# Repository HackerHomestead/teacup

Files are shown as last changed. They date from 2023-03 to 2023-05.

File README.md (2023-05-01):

# Tea Cup Tinker Board

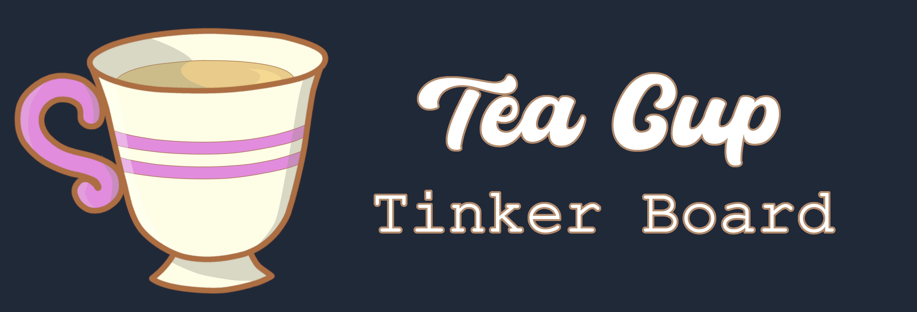
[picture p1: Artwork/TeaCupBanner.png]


The *Tea Cup* is a Tinker Board built on the *Ingenic T31* MIPS CPU, which is
specialised for Video & Audio Applications, and has highly integrated support
for multiple interfaces, LCD's, SD Card, Ethernet and more.

Designed with the community in mind, the *Tea Cup* is going to be ideal for
Kids, Tweens and Teens, and adults alike, to tinker with hardware and software
inside of an interface designed with ease-of-use and simplicity, but never 
locking the user down to a limited API or enviroment.

This project is currently in alpha, with a small team working on it, you can
join our [commuinty Discord Server](https://discord.gg/nxjvqgFQgJ)

----
## RevA Board Pictures
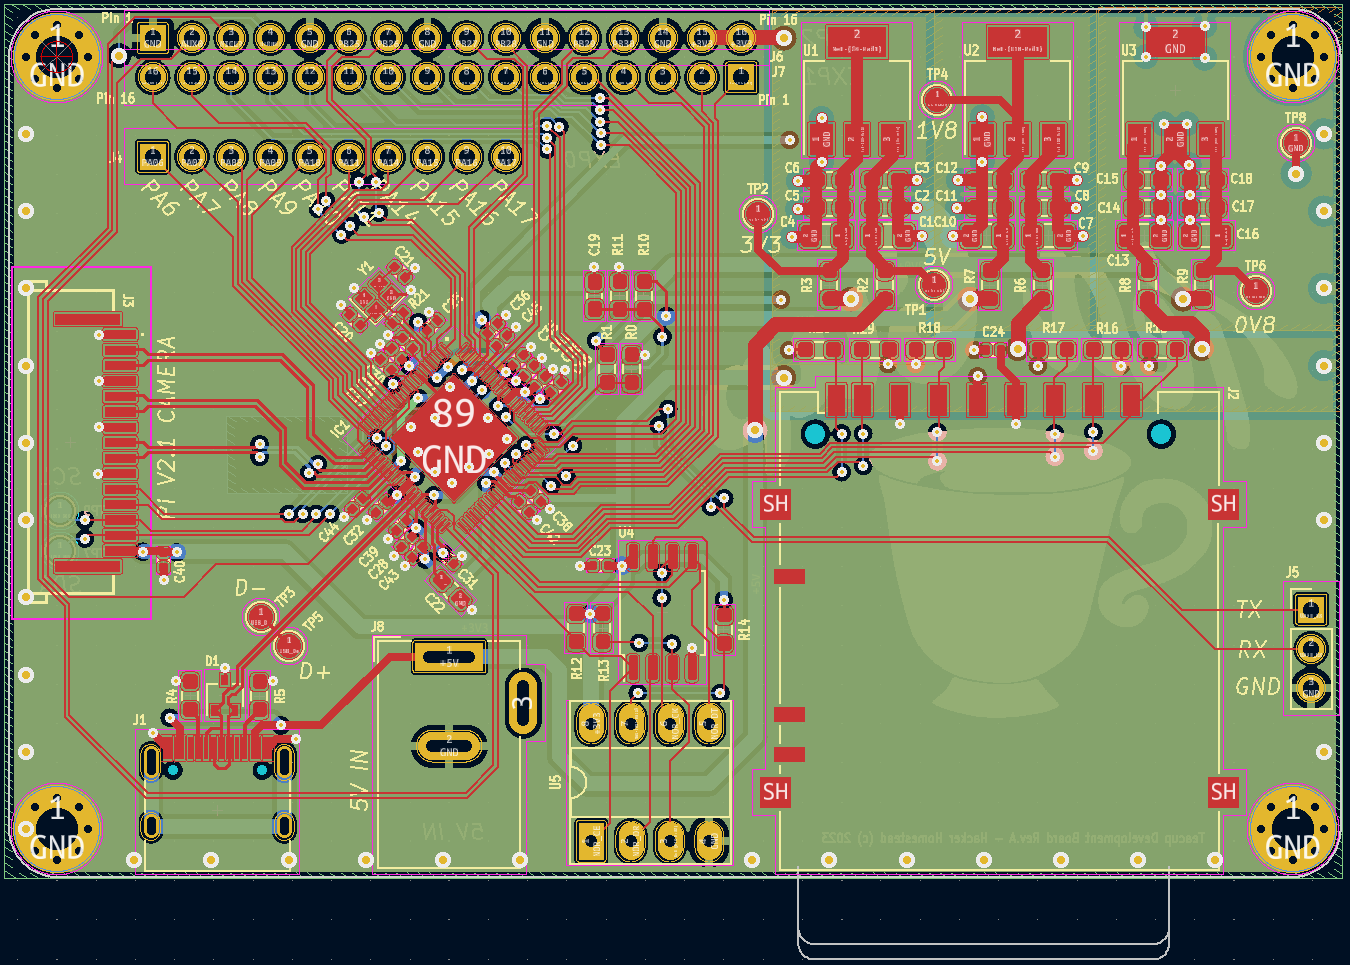
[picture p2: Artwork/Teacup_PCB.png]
boardpic1

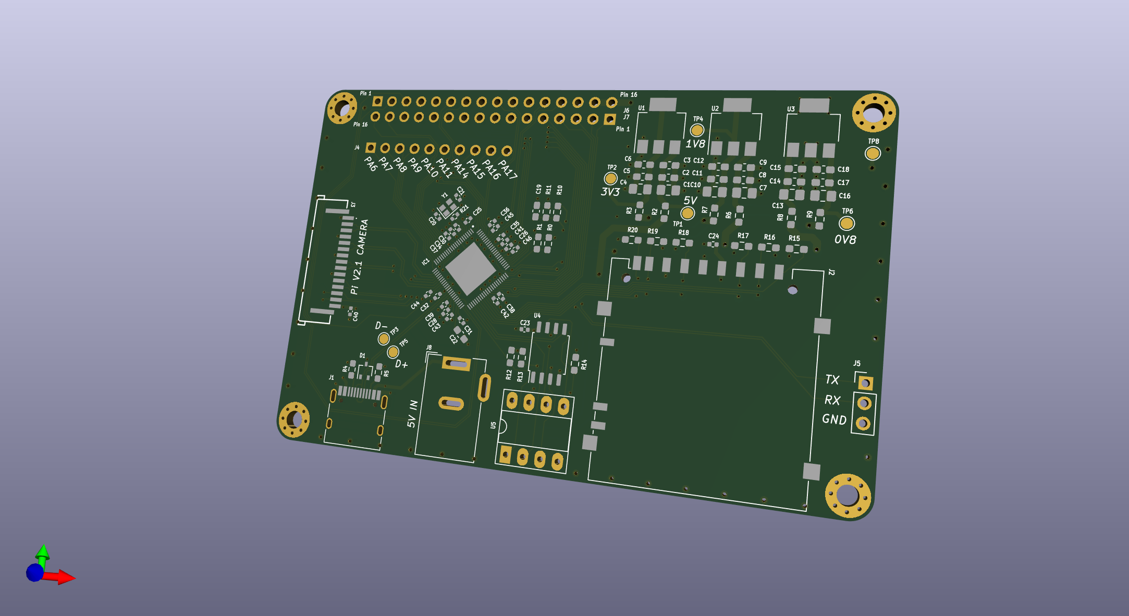
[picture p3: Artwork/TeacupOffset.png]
boardpic2

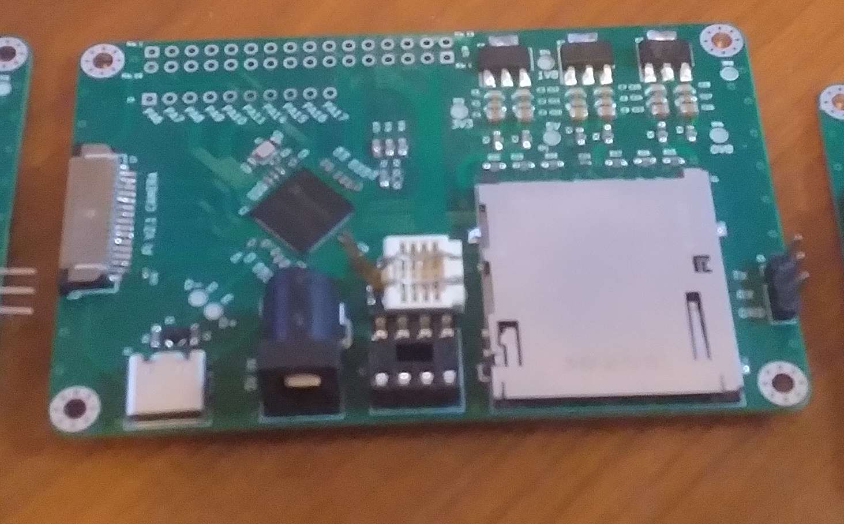
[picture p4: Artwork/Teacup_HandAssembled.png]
boardpic3


----
## Tools We Use
*All* of the work we are doing on Tea Cup, and any future projects are strictly
open-source only whenever possible, This means we do not distrubiute any CAD, 
Code, Docs, or any other files in any format that is not an open-source, Free or
FOSS Package, this is to ensure anyone can join development, and use our work in
their own endevours.

Having this in mind, the tools we are using in this project are:
* FreeCAD
* KiCad
* binwalk
* Ghidra
* GIMP

----
## Currently Working on:
* Getting an up-to-date SDK from ingenic
* Compiling uboot and attempting to create our own kernel with outdated SDK
* PCB Design for REV-A
* Testing differences between T31 Series and other Ingenic CPUs
* Finding a reliable and cheap method to get ICs from existing products
* Getting source for bulk order of T31's

## Have finished:
* REV-A Roadmap
* Compiled and ran code on the host device
* Reverse engineering of the "$1 webcam" PCB, with full Serial comms
* binwalk'd "$1 webcam" Firmware and working on Reverse Engineering
* Discord Server with management and co-ordination systems

## Long Term TODO
* Check out the master [Teacup project board](https://github.com/users/HackerHomestead/projects/1/views/1)

## External links
* [Google Drive](https://drive.google.com/drive/u/1/folders/1BEhvPF5wQ0bi8qQTojf_yk7Au3pODrgF)
* [MIPS GCC Toolchain](https://drive.google.com/file/d/13-upgyvXytasOUA2UAwAwBOmOL2-lcfM/view)
* [Ingenic T31 Datasheet](https://drive.google.com/file/d/12MYs0BrT4tRH-UkWt7oT5_zm6LXiKhQJ/view)
* [Ingenic T31(ZX) SDK](https://github.com/HackerHomestead/Ingenic-SDK-T31-1.1.1-20200508)
* [Ingenic T31 Design Docs](https://drive.google.com/file/d/1u1oQInZgQonMenszIMkonlOMmzxKc2aA/view)

* [Hacker Homestead YouTube Channel](https://www.youtube.com/@hackerhomestead)
* [WLTechBlog](https://www.youtube.com/@wltechblog6330)
----
## Thanks
To everyone who has worked with us on Tea Cup, we thank you sincerely. It has
been, and will continue to be an honour working with you.

Thank you so much to the **core-dev** team for your continued work and effort 
with us on Tea Cup, without you this would have been impossible.  
* [HandyHacker](https://github.com/HackerHomestead)
* [CaptainRon](https://github.com/CapnRon)
* [BogdanTheGeek](https://github.com/BogdanTheGeek)

Thank you

## LICENCE
This project is under the GPL2.0 Licence. See LICENCE for more information.  
(c) 2023 HomesteadHacker

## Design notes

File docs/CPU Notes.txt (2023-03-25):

#################### Ingenic T31 (88pin QFN) ###################################

32kB Instruction cache, 32kB L1, 128kB L2
Up to 1.5GHz Clock Speed on the main CPU Core
1Gb DDR2 RAM onboard (128MB)

RISC-V Core (500MHz)
I2C, 3x UART, SPI, 2x SD, USB OTG

Internal LCD Support - 800x600 60Hz
AES256 Hardware Encode/Decode
Secure Boot
Native Video Encoding via CCD, up to 2048x2048 resolution

Audio and Video Codecs

###################### Further Features ########################################
12/24/48MHz Oscillator
3x PLL (Phase Locked Loops)
POE, POR, and other Watchdog Timers
SCL/SDA (I2C) Standards, both 100Kb/s and 400Kb/s
Full Duplex UART
64 x 8bit FIFO TX, and 64 x 11bit FIFO RX
16 or 32 Ohm Audio Output, with a ????? bit DAC

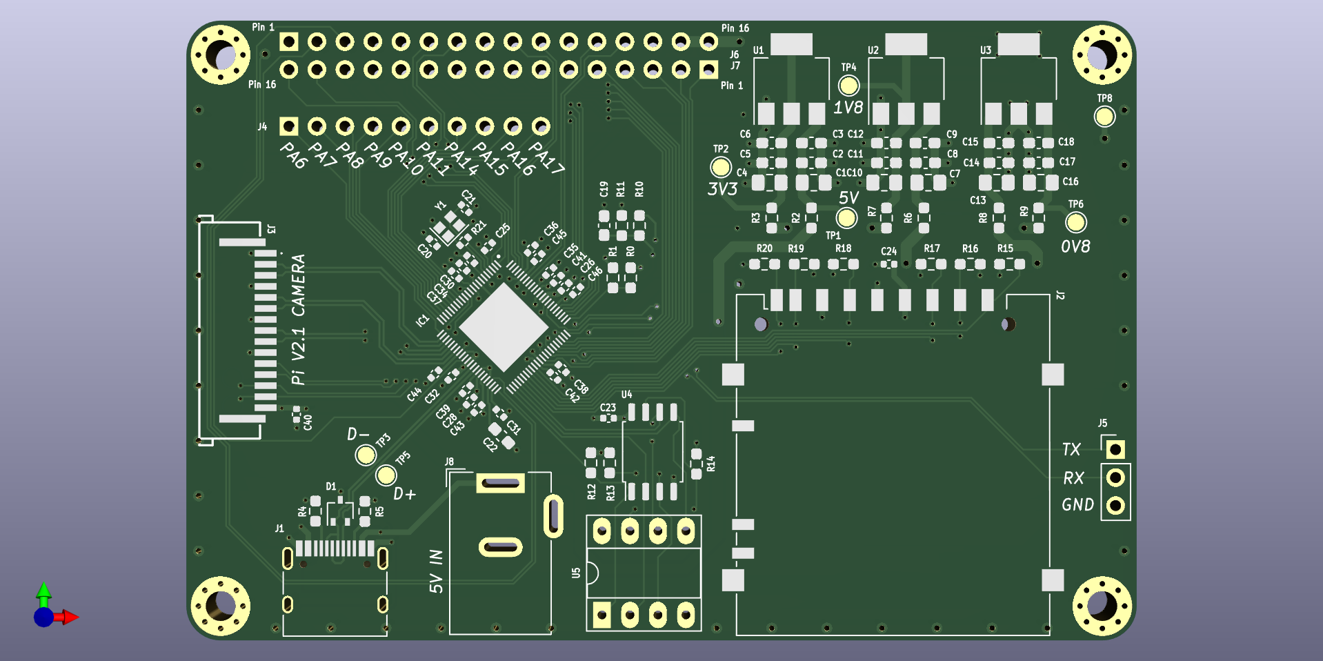
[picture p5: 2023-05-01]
Artwork/TeaCupOverhead.png

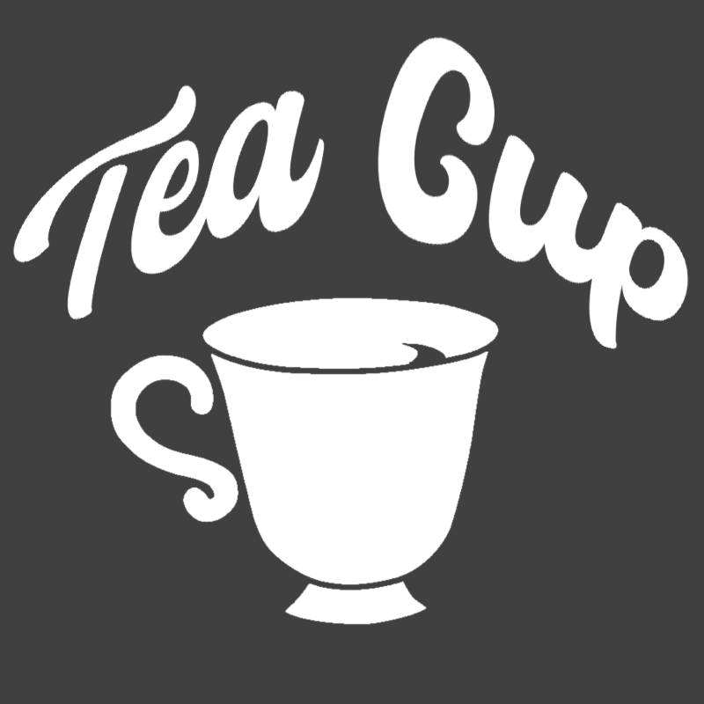
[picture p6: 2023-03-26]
Artwork/TeaCupBW.png

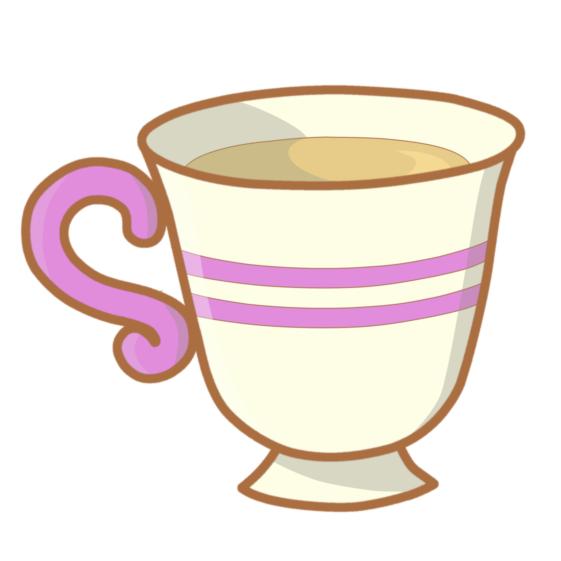
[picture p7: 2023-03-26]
Artwork/TeaCupFull.png

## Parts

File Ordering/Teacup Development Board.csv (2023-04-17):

null | Sourced | Placed | References | Value | Footprint | Quantity
1 |  |  | C23, C24, C25, C26, C28, C30, C31, C32, C34, C35, C36, C37, C38, C39, C40, C41, C42, C43, C44, C45, C46 | 100nF | C_0402_1005Metric | 21
2 |  |  | C3, C6, C9, C12, C15, C18, C19 | 100nF | C_0603_1608Metric_Pad1.08x0.95mm_HandSolder | 7
3 |  |  | C1, C4, C7, C10, C13, C16 | 10uF | C_0805_2012Metric_Pad1.18x1.45mm_HandSolder | 6
4 |  |  | C2, C5, C8, C11, C14, C17 | 1uF | C_0603_1608Metric_Pad1.08x0.95mm_HandSolder | 6
5 |  |  | C20, C21 | 12pF | C_0402_1005Metric | 2
6 |  |  | C22 | 4.7uF | C_0603_1608Metric_Pad1.08x0.95mm_HandSolder | 1
7 |  |  | R0, R1, R10, R11, R12, R13, R14 | 100k | R_0603_1608Metric_Pad0.98x0.95mm_HandSolder | 7
8 |  |  | R2, R3, R6, R7, R8, R9 | 0R | R_0603_1608Metric_Pad0.98x0.95mm_HandSolder | 6
9 |  |  | R15, R16, R17, R18, R19, R20 | 47k | R_0603_1608Metric_Pad0.98x0.95mm_HandSolder | 6
10 |  |  | R4, R5 | 5k1 | R_0603_1608Metric_Pad0.98x0.95mm_HandSolder | 2
11 |  |  | R21 | 1M | R_0402_1005Metric | 1
12 |  |  | D1 | D_TVS_Dual_AAC | SOT-323_SC-70 | 1
13 |  |  | U1 | AZ1117-3.3 | SOT-223-3_TabPin2 | 1
14 |  |  | U2 | AZ1117-1.8 | SOT-223-3_TabPin2 | 1
15 |  |  | U3 | MCP1826S | SOT-223-3_TabPin2 | 1
16 |  |  | U4 | W25Q32JVSS | SOIC-8_5.23x5.23mm_P1.27mm | 1
17 |  |  | Y1 | 24 MHz | Crystal_SMD_2016-4Pin_2.0x1.6mm | 1
18 |  |  | IC1 | T31ZX | QFN35P900X900X90-89N-D | 1
19 |  |  | J1 | USB Type-C | USB_C_Receptacle_HRO_TYPE-C-31-M-12 | 1
20 |  |  | J2 | SD_Card | SD_Hirose_DM1AA_SF_PEJ82 | 1
21 |  |  | J3 | SFW15R-2STE1LF | SFW15R2STE1LF | 1
22 |  |  | J8 | DC_IN | BarrelJack_Wuerth_6941xx301002 | 1

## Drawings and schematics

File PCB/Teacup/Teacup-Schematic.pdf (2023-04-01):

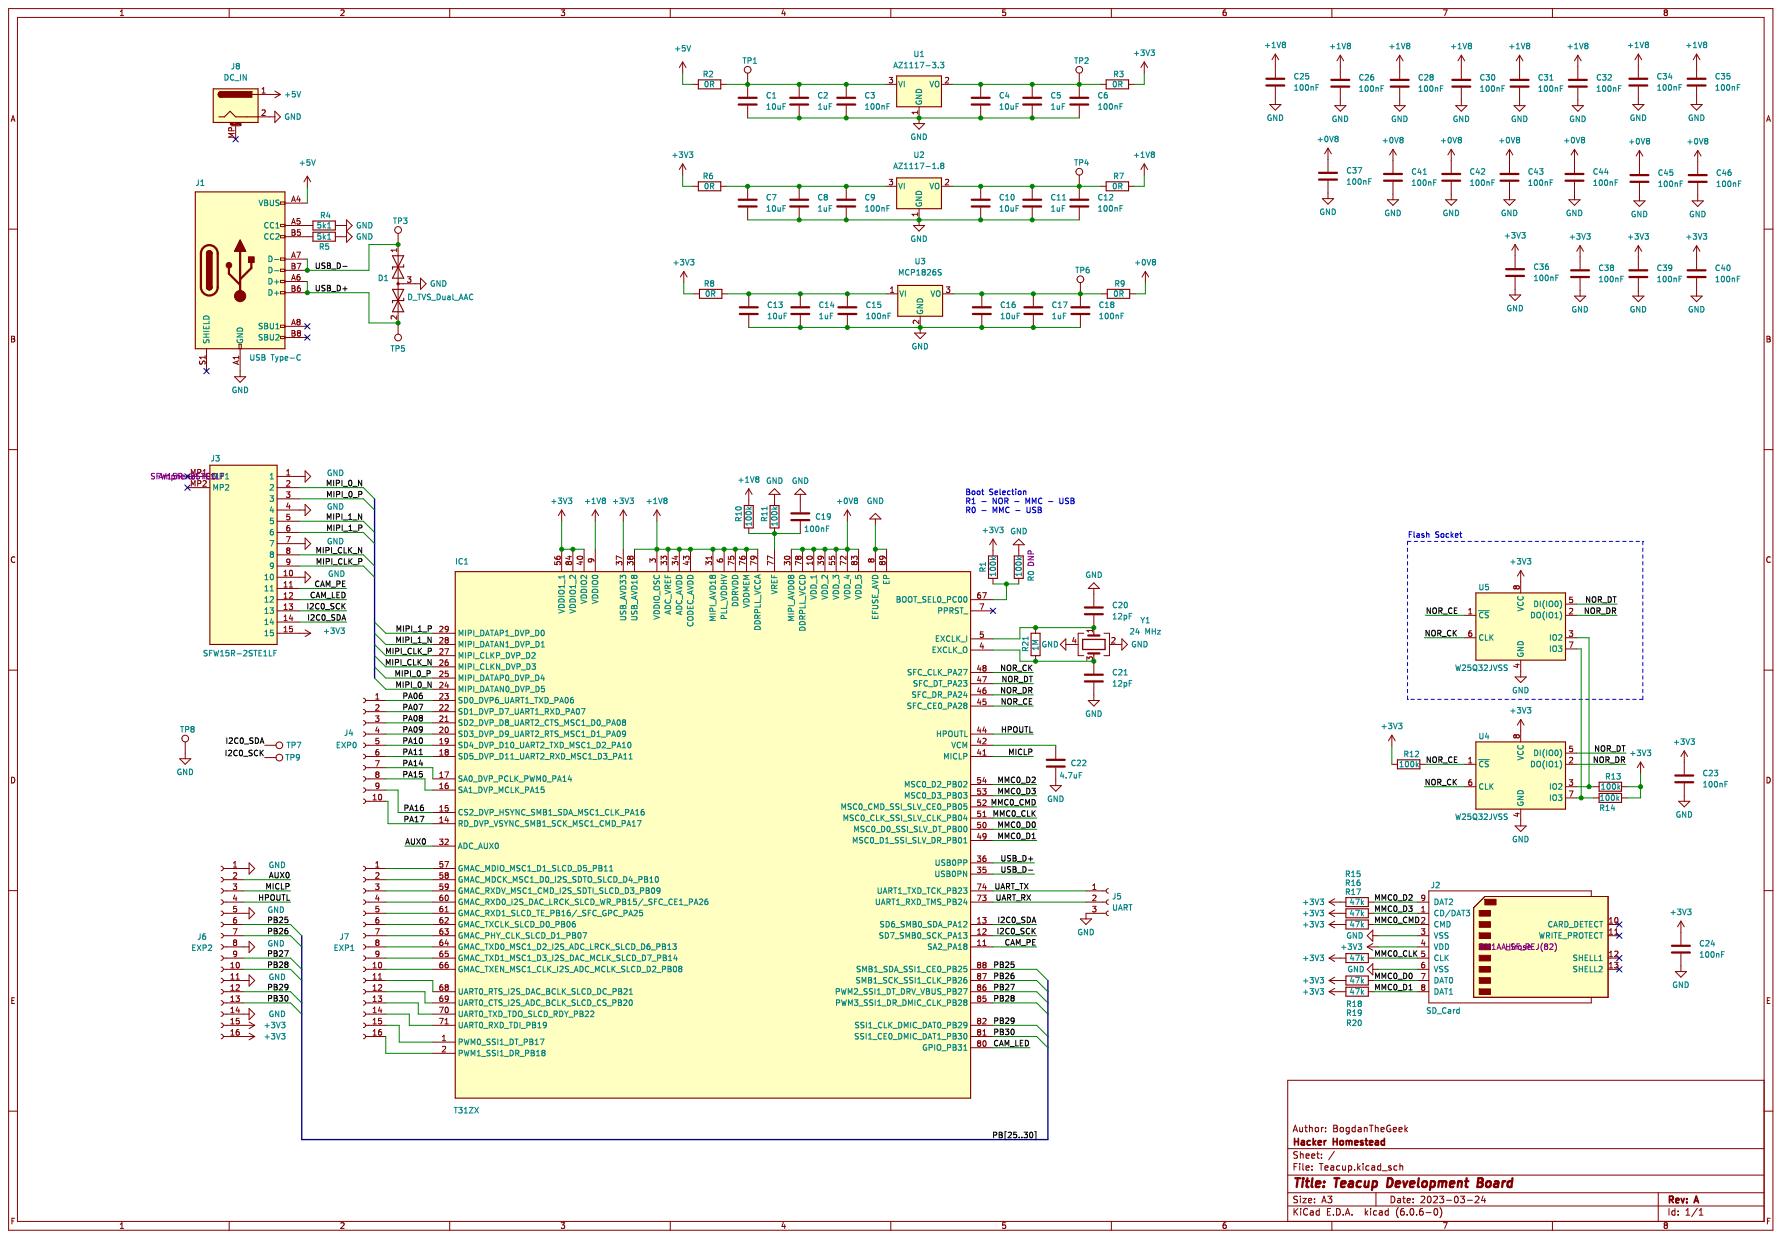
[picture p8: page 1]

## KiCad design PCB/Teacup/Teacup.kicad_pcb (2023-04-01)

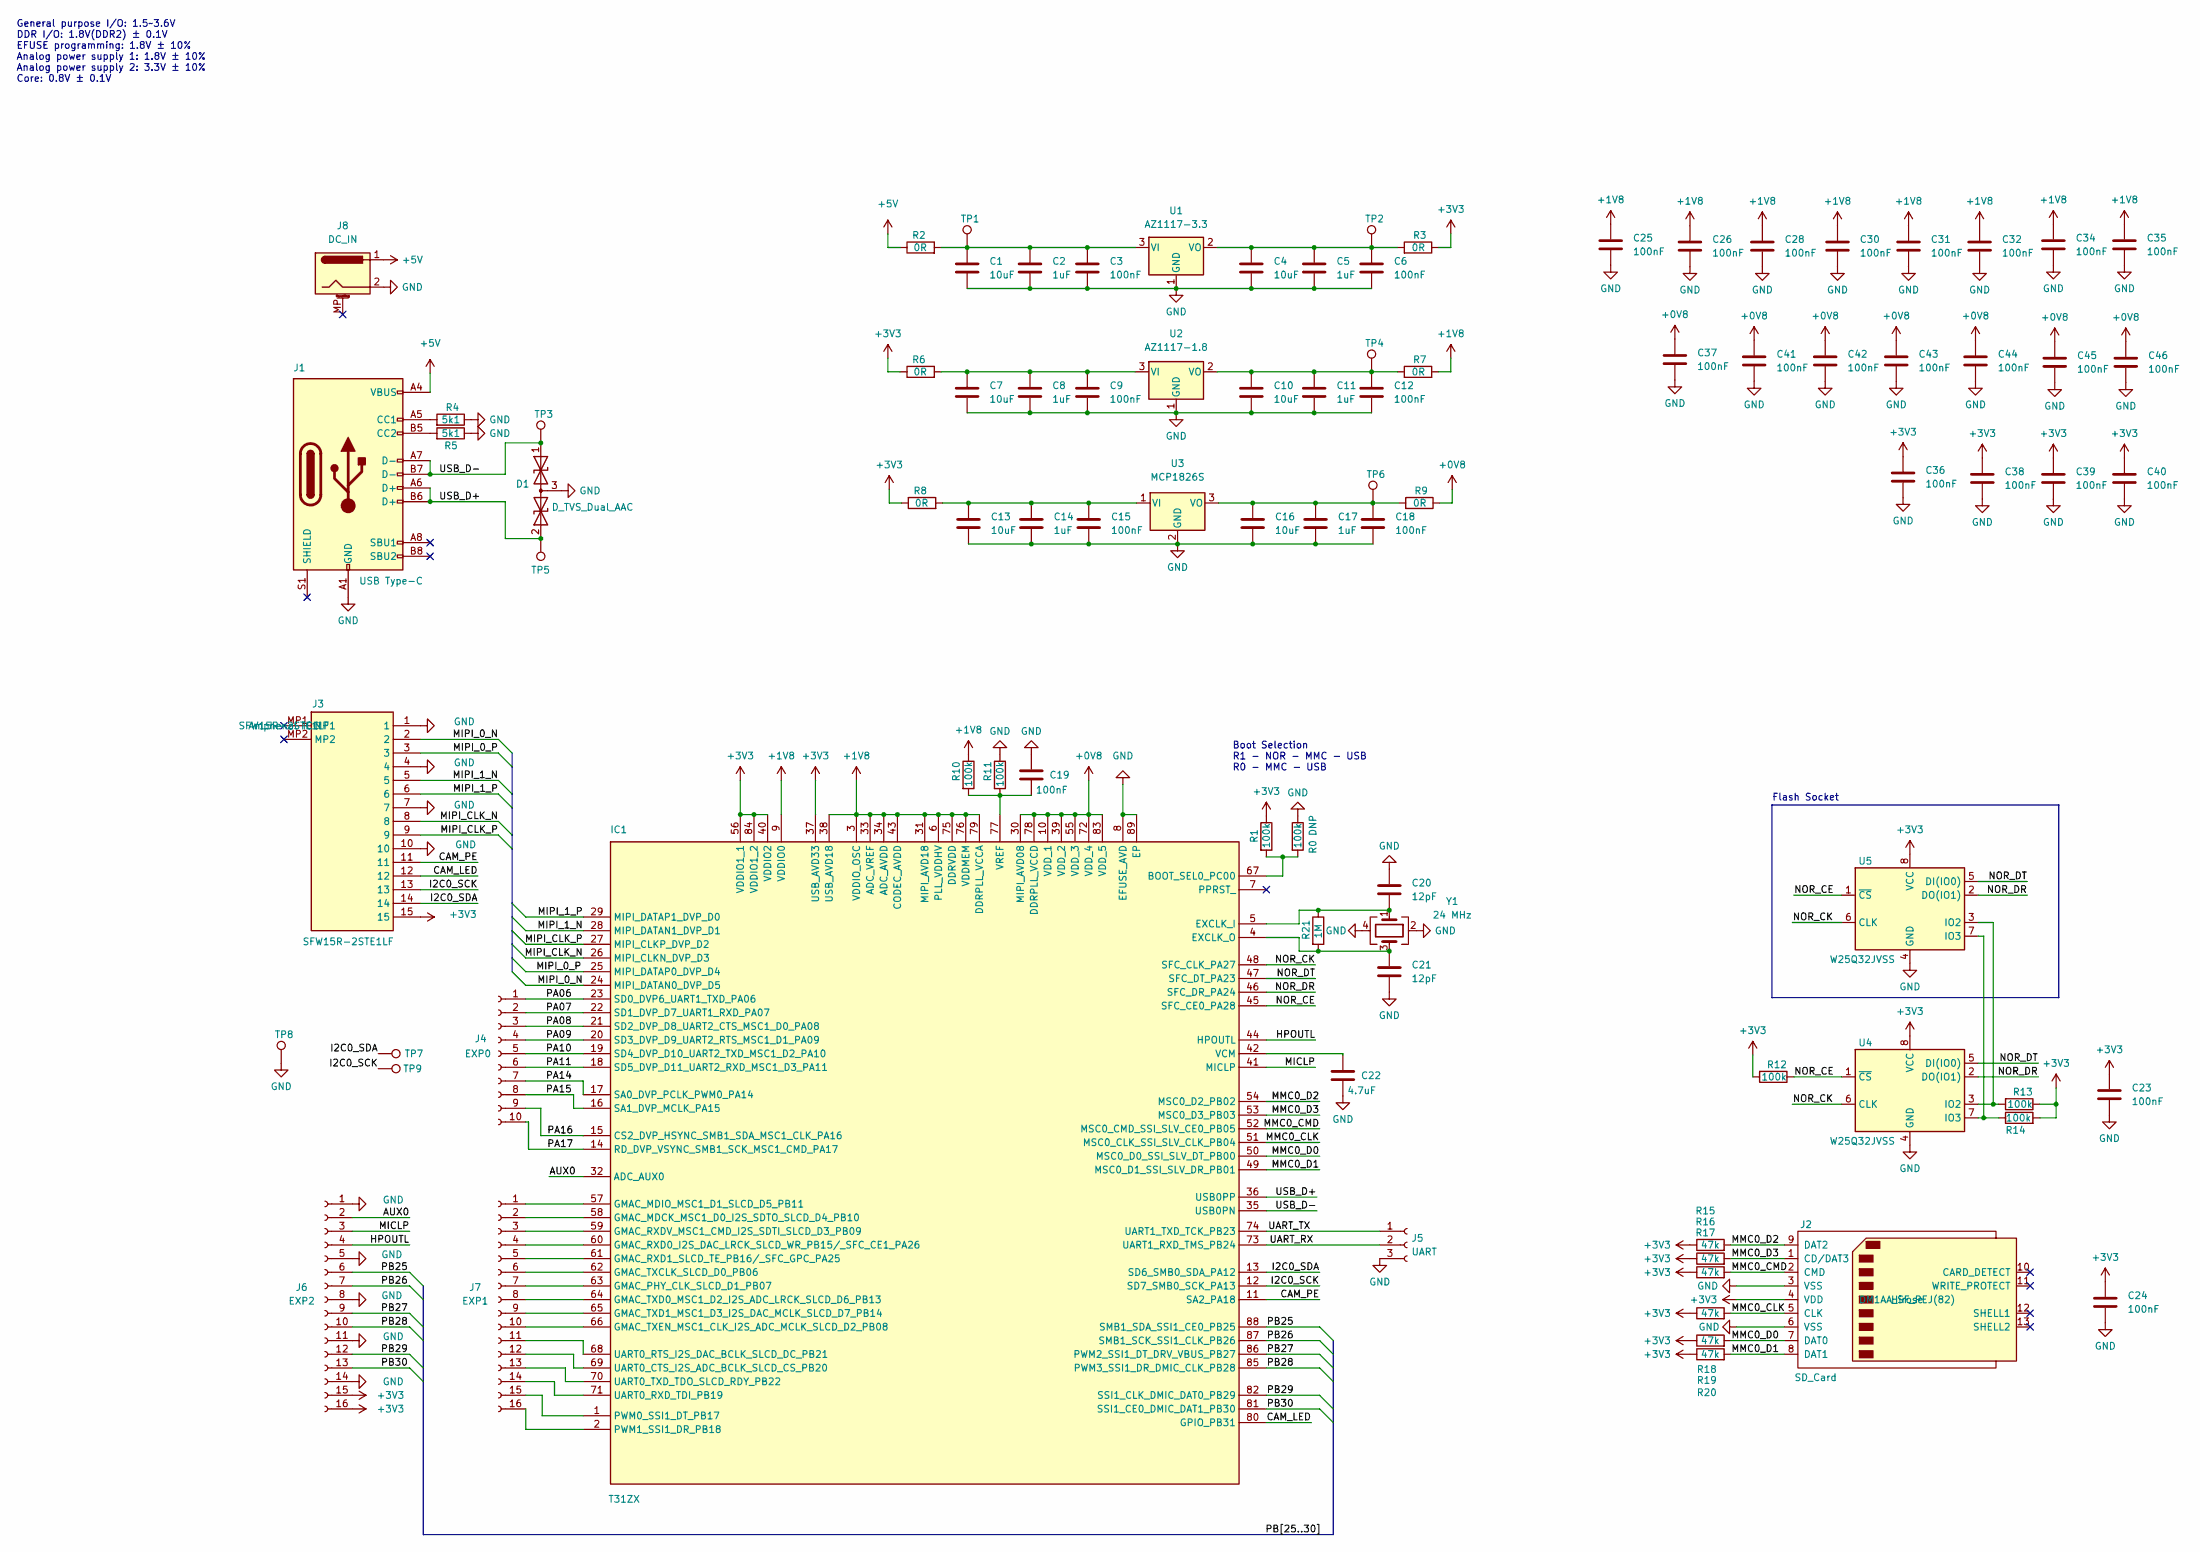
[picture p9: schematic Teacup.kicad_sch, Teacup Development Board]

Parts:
C1, C4, C7, C10, C13, C16: 10uF; C_0805_2012Metric_Pad1.18x1.45mm_HandSolder
C2, C5, C8, C11, C14, C17: 1uF; C_0603_1608Metric_Pad1.08x0.95mm_HandSolder
C3, C6, C9, C12, C15, C18, C19: 100nF; C_0603_1608Metric_Pad1.08x0.95mm_HandSolder
C20, C21: 12pF; C_0402_1005Metric
C22: 4.7uF; C_0603_1608Metric_Pad1.08x0.95mm_HandSolder
C23, C24, C25, C26, C28, C30, C31, C32, C34, C35, C36, C37, C38, C39, C40, C41, C42, C43, C44, C45, C46: 100nF; C_0402_1005Metric
D1: D_TVS_Dual_AAC; SOT-323_SC-70; Manufacturer Part Number PESD5V0U2BT,215
IC1: T31ZX; QFN35P900X900X90-89N-D; Mouser Part Number 870-T31ZX
J1: USB Type-C; USB_C_Receptacle_HRO_TYPE-C-31-M-12; Manufacturer Part Number TYPE-C-31-M-12 (USB4105-GF-A)
J2: SD_Card; SD_Hirose_DM1AA_SF_PEJ82; Manufacturer Part Number DM1AA_SF_PEJ(82)
J3: SFW15R-2STE1LF; SFW15R2STE1LF; Mouser Part Number 649-SFW15R-2STE1LF
J4: EXP0; PinHeader_1x10_P2.54mm_Vertical
J5: UART; PinHeader_1x03_P2.54mm_Vertical
J6: EXP2; PinHeader_1x16_P2.54mm_Vertical
J7: EXP1; PinHeader_1x16_P2.54mm_Vertical
J8: DC_IN; BarrelJack_Wuerth_6941xx301002
R0, R1, R10, R11, R12, R13, R14: 100k; R_0603_1608Metric_Pad0.98x0.95mm_HandSolder
R2, R3, R6, R7, R8, R9: 0R; R_0603_1608Metric_Pad0.98x0.95mm_HandSolder
R4, R5: 5k1; R_0603_1608Metric_Pad0.98x0.95mm_HandSolder
R15, R16, R17, R18, R19, R20: 47k; R_0603_1608Metric_Pad0.98x0.95mm_HandSolder
R21: 1M; R_0402_1005Metric
TP1, TP2, TP3, TP4, TP5, TP6, TP7, TP8, TP9: TestPoint; TestPoint_Pad_D1.5mm
U1: AZ1117-3.3; SOT-223-3_TabPin2; Manufacturer Part Number AZ1117IH-3.3TRG1
U2: AZ1117-1.8; SOT-223-3_TabPin2; Manufacturer Part Number AZ1117(CH)-1.8
U3: MCP1826S; SOT-223-3_TabPin2; Manufacturer Part Number MCP1826S
U4: W25Q32JVSS; SOIC-8_5.23x5.23mm_P1.27mm; Manufacturer Part Number W25Q32JVSS
U5: W25Q32JVSS; DIP-8_W7.62mm_Socket_LongPads
Y1: 24 MHz; Crystal_SMD_2016-4Pin_2.0x1.6mm; Manufacturer Part Number NX2016SA-24MHZ-EXS00A-CS07553

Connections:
+0V8: C37.1, C41.1, C42.1, C43.1, C44.1, C45.1, C46.1, IC1.10 (VDD_1), IC1.30 (MIPI_AVD08), IC1.39 (VDD_2), IC1.55 (VDD_3), IC1.72 (VDD_4), IC1.78 (DDRPLL_VCCD), IC1.83 (VDD_5), R9.1
+1V8: C25.1, C26.1, C28.1, C30.1, C31.1, C32.1, C34.1, C35.1, IC1.3 (VDDIO_OSC), IC1.6 (PLL_VDDHV), IC1.9 (VDDIO0), IC1.31 (MIPI_AVD18), IC1.33 (ADC_VREF), IC1.34 (ADC_AVDD), IC1.38 (USB_AVD18), IC1.43 (CODEC_AVDD), IC1.75 (DDRVDD), IC1.76 (VDDMEM), IC1.79 (DDRPLL_VCCA), R7.1, R10.1
+3V3: C23.1, C24.1, C36.1, C38.1, C39.1, C40.1, IC1.37 (USB_AVD33), IC1.40 (VDDIO2), IC1.56 (VDDIO1_1), IC1.84 (VDDIO1_2), J2.4 (VDD), J3.15, J6.15, J6.16, R1.1, R3.1, R6.1, R8.1, R12.2, R13.1, R14.2, R15.1, R16.1, R17.1, R18.1, R19.1, R20.1, U4.8 (VCC), U5.8 (VCC)
+5V: J1.A4 (VBUS), J1.A9 (VBUS), J1.B4 (VBUS), J1.B9 (VBUS), J8.1, R2.1
/AUX0: IC1.32 (ADC_AUX0), J6.2
/CAM_LED: IC1.80 (GPIO_PB31), J3.12
/CAM_PE: IC1.11 (SA2_PA18), J3.11
/HPOUTL: IC1.44 (HPOUTL), J6.4
/I2C0_SCK: IC1.12 (SD7_SMB0_SCK_PA13), J3.13, TP9.1
/I2C0_SDA: IC1.13 (SD6_SMB0_SDA_PA12), J3.14, TP7.1
/MICLP: IC1.41 (MICLP), J6.3
/MIPI_0_N: IC1.24 (MIPI_DATAN0_DVP_D5), J3.2
/MIPI_0_P: IC1.25 (MIPI_DATAP0_DVP_D4), J3.3
/MIPI_1_N: IC1.28 (MIPI_DATAN1_DVP_D1), J3.5
/MIPI_1_P: IC1.29 (MIPI_DATAP1_DVP_D0), J3.6
/MIPI_CLK_N: IC1.26 (MIPI_CLKN_DVP_D3), J3.8
/MIPI_CLK_P: IC1.27 (MIPI_CLKP_DVP_D2), J3.9
/MMC0_CLK: IC1.51 (MSC0_CLK_SSI_SLV_CLK_PB04), J2.5 (CLK), R18.2
/MMC0_CMD: IC1.52 (MSC0_CMD_SSI_SLV_CE0_PB05), J2.2 (CMD), R17.2
/MMC0_D0: IC1.50 (MSC0_D0_SSI_SLV_DT_PB00), J2.7 (DAT0), R19.2
/MMC0_D1: IC1.49 (MSC0_D1_SSI_SLV_DR_PB01), J2.8 (DAT1), R20.2
/MMC0_D2: IC1.54 (MSC0_D2_PB02), J2.9 (DAT2), R15.2
/MMC0_D3: IC1.53 (MSC0_D3_PB03), J2.1 (CD/DAT3), R16.2
/NOR_CE: IC1.45 (SFC_CE0_PA28), R12.1, U4.1 (~CS), U5.1 (~CS)
/NOR_CK: IC1.48 (SFC_CLK_PA27), U4.6 (CLK), U5.6 (CLK)
/NOR_DR: IC1.46 (SFC_DR_PA24), U4.2 (DO(IO1)), U5.2 (DO(IO1))
/NOR_DT: IC1.47 (SFC_DT_PA23), U4.5 (DI(IO0)), U5.5 (DI(IO0))
/PA06: IC1.23 (SD0_DVP6_UART1_TXD_PA06), J4.1
/PA07: IC1.22 (SD1_DVP_D7_UART1_RXD_PA07), J4.2
/PA08: IC1.21 (SD2_DVP_D8_UART2_CTS_MSC1_D0_PA08), J4.3
/PA09: IC1.20 (SD3_DVP_D9_UART2_RTS_MSC1_D1_PA09), J4.4
/PA10: IC1.19 (SD4_DVP_D10_UART2_TXD_MSC1_D2_PA10), J4.5
/PA11: IC1.18 (SD5_DVP_D11_UART2_RXD_MSC1_D3_PA11), J4.6
/PA14: IC1.17 (SA0_DVP_PCLK_PWM0_PA14), J4.7
/PA15: IC1.16 (SA1_DVP_MCLK_PA15), J4.8
/PA16: IC1.15 (CS2_DVP_HSYNC_SMB1_SDA_MSC1_CLK_PA16), J4.9
/PA17: IC1.14 (RD_DVP_VSYNC_SMB1_SCK_MSC1_CMD_PA17), J4.10
/PB25: IC1.88 (SMB1_SDA_SSI1_CE0_PB25), J6.6
/PB26: IC1.87 (SMB1_SCK_SSI1_CLK_PB26), J6.7
/PB27: IC1.86 (PWM2_SSI1_DT_DRV_VBUS_PB27), J6.9
/PB28: IC1.85 (PWM3_SSI1_DR_DMIC_CLK_PB28), J6.10
/PB29: IC1.82 (SSI1_CLK_DMIC_DAT0_PB29), J6.12
/PB30: IC1.81 (SSI1_CE0_DMIC_DAT1_PB30), J6.13
/UART_RX: IC1.73 (UART1_RXD_TMS_PB24), J5.2
/UART_TX: IC1.74 (UART1_TXD_TCK_PB23), J5.1
/USB_D+: D1.2 (A2), IC1.36 (USB0PP), J1.A6 (D+), J1.B6 (D+), TP5.1
/USB_D-: D1.1 (A1), IC1.35 (USB0PN), J1.A7 (D-), J1.B7 (D-), TP3.1
GND: C1.2, C2.2, C3.2, C4.2, C5.2, C6.2, C7.2, C8.2, C9.2, C10.2, C11.2, C12.2, C13.2, C14.2, C15.2, C16.2, C17.2, C18.2, C19.1, C20.1, C21.2, C22.2, C23.2, C24.2, C25.2, C26.2, C28.2, C30.2, C31.2, C32.2, C34.2, C35.2, C36.2, C37.2, C38.2, C39.2, C40.2, C41.2, C42.2, C43.2, C44.2, C45.2, C46.2, D1.3 (common), IC1.8 (EFUSE_AVD), IC1.89 (EP), J1.A1 (GND), J1.A12 (GND), J1.B1 (GND), J1.B12 (GND), J2.3 (VSS), J2.6 (VSS), J3.1, J3.4, J3.7, J3.10, J5.3, J6.1, J6.5, J6.8, J6.11, J6.14, J8.2, R0.1, R4.1, R5.1, R11.1, TP8.1, U1.1 (GND), U2.1 (GND), U3.2 (GND), U4.4 (GND), U5.4 (GND), Y1.2, Y1.4
unnamed: C1.1, C2.1, C3.1, R2.2, TP1.1, U1.3 (VI)
unnamed: C4.1, C5.1, C6.1, R3.2, TP2.1, U1.2 (VO)
unnamed: C7.1, C8.1, C9.1, R6.2, U2.3 (VI)
unnamed: C10.1, C11.1, C12.1, R7.2, TP4.1, U2.2 (VO)
unnamed: C13.1, C14.1, C15.1, R8.2, U3.1 (VI)
unnamed: C16.1, C17.1, C18.1, R9.2, TP6.1, U3.3 (VO)
unnamed: C19.2, IC1.77 (VREF), R10.2, R11.2
unnamed: C20.2, IC1.5 (EXCLK_I), R21.1, Y1.1
unnamed: C21.1, IC1.4 (EXCLK_O), R21.2, Y1.3
unnamed: C22.1, IC1.42 (VCM)
unnamed: IC1.1 (PWM0_SSI1_DT_PB17), J7.15
unnamed: IC1.2 (PWM1_SSI1_DR_PB18), J7.16
unnamed: IC1.57 (GMAC_MDIO_MSC1_D1_SLCD_D5_PB11), J7.1
unnamed: IC1.58 (GMAC_MDCK_MSC1_D0_I2S_SDTO_SLCD_D4_PB10), J7.2
unnamed: IC1.59 (GMAC_RXDV_MSC1_CMD_I2S_SDTI_SLCD_D3_PB09), J7.3
unnamed: IC1.60 (GMAC_RXD0_I2S_DAC_LRCK_SLCD_WR_PB15/_SF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), J7.4
unnamed: IC1.61 (GMAC_RXD1_SLCD_TE_PB16/_SFC_GPC_PA25), J7.5
unnamed: IC1.62 (GMAC_TXCLK_SLCD_D0_PB06), J7.6
unnamed: IC1.63 (GMAC_PHY_CLK_SLCD_D1_PB07), J7.7
unnamed: IC1.64 (GMAC_TXD0_MSC1_D2_I2S_ADC_LRCK_SLCD_D6_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), J7.8
unnamed: IC1.65 (GMAC_TXD1_MSC1_D3_I2S_DAC_MCLK_SLCD_D7_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), J7.9
unnamed: IC1.66 (GMAC_TXEN_MSC1_CLK_I2S_ADC_MCLK_SLCD_D2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), J7.10
unnamed: IC1.67 (BOOT_SEL0_PC00), R0.2, R1.2
unnamed: IC1.68 (UART0_RTS_I2S_DAC_BCLK_SLCD_DC_PB21), J7.11
unnamed: IC1.69 (UART0_CTS_I2S_ADC_BCLK_SLCD_CS_PB20), J7.12
unnamed: IC1.70 (UART0_TXD_TDO_SLCD_RDY_PB22), J7.13
unnamed: IC1.71 (UART0_RXD_TDI_PB19), J7.14
unnamed: J1.A5 (CC1), R4.2
unnamed: J1.B5 (CC2), R5.2
unnamed: R13.2, U4.3 (IO2), U5.3 (IO2)
unnamed: R14.1, U4.7 (IO3), U5.7 (IO3)

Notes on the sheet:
Boot Selection R1 - NOR - MMC - USB R0 - MMC - USB
Flash Socket
General purpose I/O: 1.5~3.6V DDR I/O: 1.8V(DDR2) ± 0.1V EFUSE programming: 1.8V ± 10% Analog power supply 1: 1.8V ± 10% Analog power supply 2: 3.3V ± 10% Core: 0.8V ± 0.1V

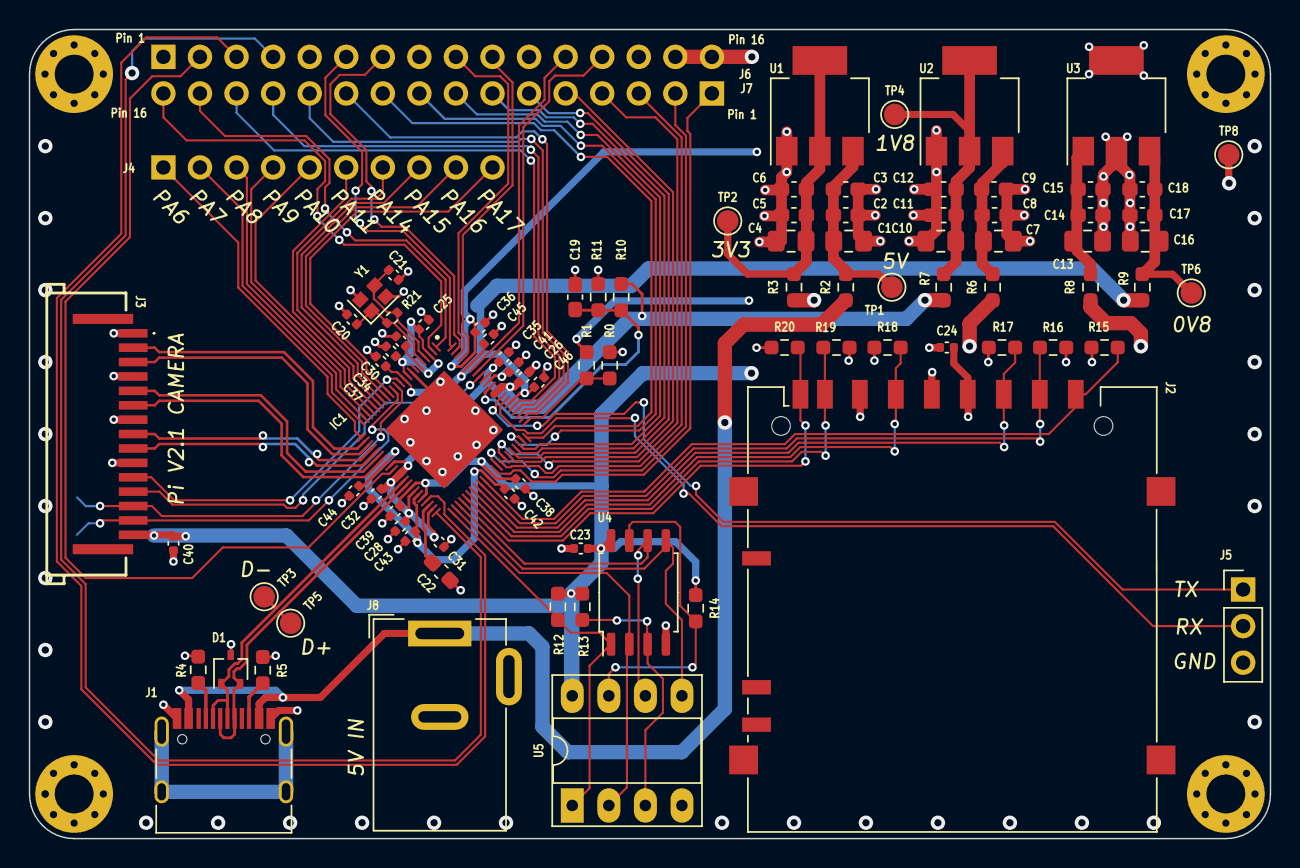
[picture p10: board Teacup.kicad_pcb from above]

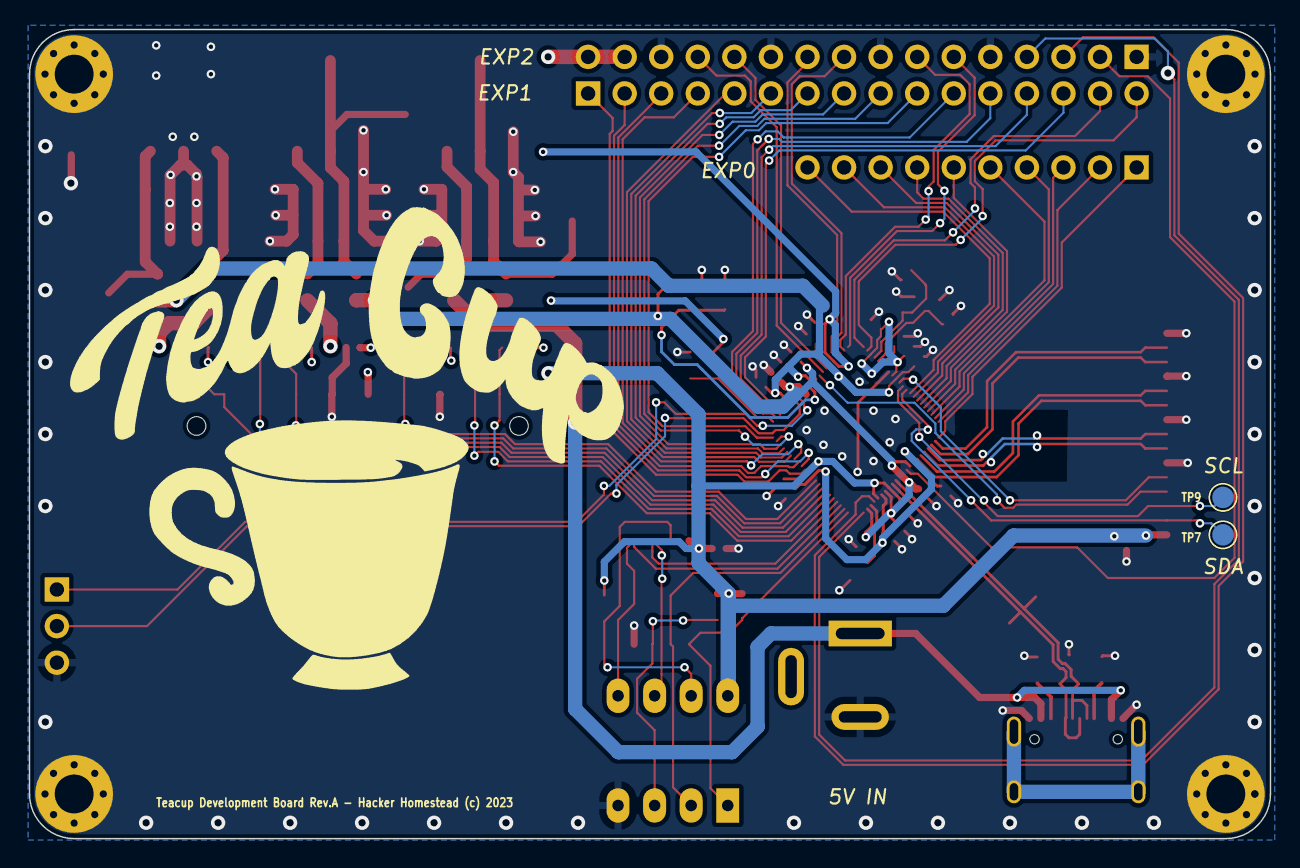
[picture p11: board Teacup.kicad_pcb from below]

Board: 4 copper layers, 86.2 x 56.2 mm, 90 parts (2 on the bottom side), 79 nets.

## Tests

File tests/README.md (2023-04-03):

# Testing toolchains and branches

Testing methods for compilation, creating toolkits, SDK, uboot, other Firmware 
etc. None of the contents held here are final, fully functional or designed to
be used by anyone but testing devs. Do not be surprised if the binaries, SDK's
tools etc **do not work**

## Branch listings
* mips64aws - 64bit MIPS AWS used to compile C & C++ Programs (ADBeta)

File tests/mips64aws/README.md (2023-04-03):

# mips64aws

A few tools and programs written in C and C++ using a MIPSel 64bit AWS host,
using compiler flgas to change the mabi and arch (see compile-for-t31.sh).

These were confirmed to work on a T31 and T21 based webcam running Linux, but
required static linking due to out of date libs on the webcam, as such the 
file sizes are bloated beyond normal sizes.

## Notes
Due to the static linking, C++ files are very big, but when normally dynamically
compiled, they use 11kB, while larger than C it should be fine for our auxiliary
programs stored on SD, or a complex core module.

C++ takes around 4x as long to compile using a mips64aws host, this isn't a big
problem for our final toolchain - but is a noteworthy drawback on this tier of 
machine.

These binaries were run on CaptnRons' and Handys' T31 webcam hosts with 100%
success.

----
ADBeta

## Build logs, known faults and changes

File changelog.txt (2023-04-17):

This is a placeholder for a better changelog

There comes a point where we need to draw a line in the sand on a release

As an inital order is being built the RevA release is 20230413

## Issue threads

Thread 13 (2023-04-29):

Filing an issue test

HackerHomestead, 2023-04-29:
going to see if I can pick this issue up in a project demo board

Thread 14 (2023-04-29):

1st Manufacturing Run - PCBWay TurnKey Order RevA

HackerHomestead, 2023-04-29:

HackerHomestead, 2023-04-29:
## Status

- [] Submit Design and BOM
- [] Acceptance
- [] Pay for Order
- [] PCB Production
- [] Parts Sourcing
- [] Production
- [] Shipping
- [] HH Testing

HackerHomestead, 2023-05-04:
Checked no update

HackerHomestead, 2023-05-09:
Checked, no update

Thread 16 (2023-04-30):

Get Permission to use font

HackerHomestead, 2023-04-30:
email debutstudio21@gmail.com to make sure he's okay with us using "Batuphat Script" font

HackerHomestead, 2023-05-06:
Whohoo we have permission to use the font in the original artwork
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

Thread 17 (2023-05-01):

Support research suggestions by IThames

HackerHomestead, 2023-05-01:
TODO from today's discussion:
- [ ] Are any of the IMX sensors supported, can support be added for new sensors?
- [x] Is FPU included in T31?
+ [ ] Any support being planned for more recent versions of Linux kernel, such as 6.x?

HackerHomestead, 2023-05-01:
Hardware FPU is included per
https://www.lumissil.com/assets/newsletter/Issue07_Aug_2021/T31-Video-Processor_newsletter-Aug2021.pdf

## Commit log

2023-03-24 pcb: symbols and footprints
2023-03-24 pcb: teacup: project files
    [Teacup.kicad_pcb, Teacup.kicad_sch]
2023-03-25 pcb: sym: cleanup and order
    [Teacup.kicad_sch]
2023-03-25 pcb: pow + clock + usb
    [Teacup.kicad_sch]
2023-03-25 pcb: regulators
    [Teacup.kicad_sch]
2023-03-25 pcb: flash + footprints
    [Teacup.kicad_pcb, Teacup.kicad_sch]
2023-03-28 pcb: sch done, initial placement
    [Teacup.kicad_pcb, Teacup.kicad_sch]
2023-03-30 pcb: routed high speed signals
    [Teacup.kicad_pcb, Teacup.kicad_sch]
2023-03-31 pcb: routing done
    [Teacup.kicad_pcb, Teacup.kicad_sch]
2023-04-01 pcb: boms and gerbers
    [Teacup-B_Cu.gbr, Teacup-B_Mask.gbr, Teacup-B_Paste.gbr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]
2023-04-13 Submitted inital order
    [Teacup Development Board.csv]

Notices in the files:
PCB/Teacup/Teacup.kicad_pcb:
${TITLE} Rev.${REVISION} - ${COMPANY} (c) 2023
